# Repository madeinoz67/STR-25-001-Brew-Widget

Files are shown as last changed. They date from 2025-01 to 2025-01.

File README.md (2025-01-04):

# STR-25-001 Brew Widget

ESP32 Based Tilt Hydrometer

## Project Features

- All in one PCB inspired by [iSpindel - DIY electronics Hydrometer](https://www.ispindel.de/)

## Resources

Below are some handy resource links.

* [KiCad](https://www.kicad.org/) is a Cross Platform and Open Source Electronics Design Automation suite.
* [cookiecutter-kicad](https://github.com/madeinoz67/cookiecutter-kicad) a cookiecutter template for KiCad Projects.

## Authors

* **Stephen Eaton** - *Initial Work* - [github](https://github.com/madeinoz67)

See also the list of [contributors](https://github.com/madeinoz67/brew-widget/AUTHORS.rst) who participated in this project.

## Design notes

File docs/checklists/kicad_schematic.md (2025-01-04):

## KiCad Schematic Checklist - initial project setup

- [ ] Ensure the latest version of KiCad is installed and up-to-date.
- [ ] Add JLPCB Fabrication Toolkit Plugin to KiCad.
- [ ] Add JLPCB Kicad library as a submodule in kicad library folder 'git submodule add https://github.com/CDFER/JLCPCB-Kicad-Library.git'
- [ ] Add Strobotics Kicad library as a submodule in kicad library folder 'git submodule add https://github.com/madeinoz67/kicad-library.git'
- [ ] Stack-up aligns with manufacturer capabilities.
- [ ] Schematic template is set up correctly with the project name, revision, and date.

## ESP32 Schematic Checklist

- [ ] ESP32 is correctly placed and oriented, antenna has clearance.
- [ ] ESP32 is connected to the correct power and ground nets.
- [ ] GPIO 34 is only used for input.
- [ ] GPIO 35 is only used for input.
- [ ] GPIO 36 is only used for input.
- [ ] GPIO 39 is only used for input.
- [ ] Do Not Use GPIO 6 (used for flash)
- [ ] Do Not Use GPIO 7 (used for flash)
- [ ] Do Not Use GPIO 8 (used for flash)
- [ ] Do Not Use GPIO 9 (used for flash)
- [ ] Do Not Use GPIO 10 (used for flash)
- [ ] Do Not Use GPIO 11 (used for flash)

## Power Supply Schematic Checklist - schematic design

- [ ] For battery powered projects, ensure the battery management circuit is included.
- [ ] Ensure reverse polarity protection is included.
- [ ] Ensure Poly Fuses are included and sized correctly.

## KiCad Schematic Checklist - schematic design

- [ ] Ensure all components are correctly annotated.
- [ ] Ensure all components are correctly placed and connected.
- [ ] Ensure all components are correctly labeled.
- [ ] Ensure all power and ground connections are robust and able to handle the expected current.
- [ ] Ensure all components are correctly connected to the correct nets.
- [ ] Ensure all components are correctly connected to the correct power and ground nets.
- [ ] Ensure all components are correctly populated with their appropriate footprints.
- [ ] Ensure all components are correctly connected to the correct footprints.
- [ ] Ensure all components are correctly populated with their appropriate value.
- [ ] Ensure all components are correctly populated with their appropriate reference designator.
- [ ] Ensure all components are correctly populated with their appropriate part number.
- [ ] Ensure all components are correctly populated with their appropriate manufacturer's part number.
- [ ] Ensure all components are correctly populated with their appropriate manufacturer's datasheet.
- [ ] Ensure all components can handle expected voltages.
- [ ] Mark all unused pins as no connect.
- [ ] Ensure the schematic is not missing any parts.
- [ ] Ensure the schematic is not missing any power or ground connections.
- [ ] Ensure the schematic is not missing any footprints.

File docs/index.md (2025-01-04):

# Welcome to STR-25-001 Brew Widget

ESP32 Based Tilt Hydrometer based on the iSpindel

--8<-- "./README.md"

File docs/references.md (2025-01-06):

- [iSpindel - DIY electronics Hydrometer](https://www.ispindel.de/)
- Alternative Firmware - [Gravity Mon](https://mp-se.github.io/gravitymon/index.html)

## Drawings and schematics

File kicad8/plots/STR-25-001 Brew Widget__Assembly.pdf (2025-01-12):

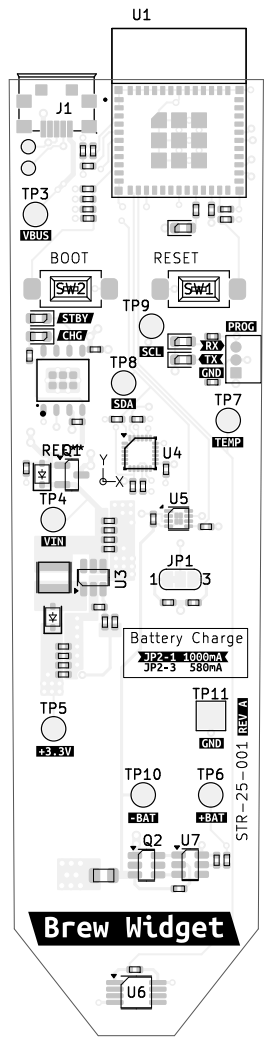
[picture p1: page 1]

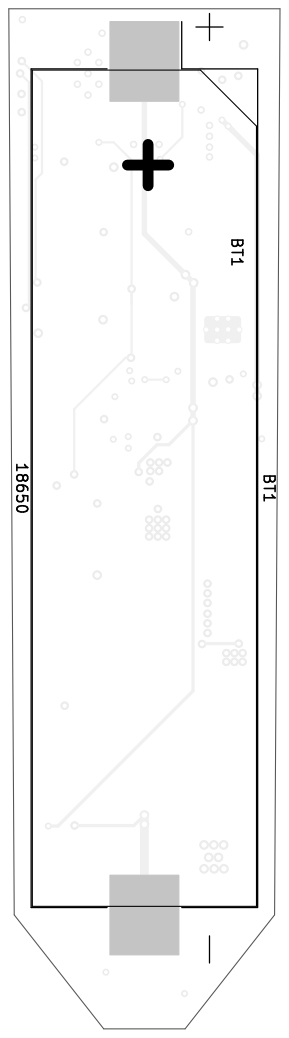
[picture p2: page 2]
D Date: 2025-01-04 KiCad; E.D.A. 8.0.7 Size: A4; Rev: A; Id: 1/1 Title: ESP32 Based Tilt Hydrometer File: STR-25-001; Brew Widget.kicad_pcb Sheet: Black; And; White; BOT Author: Stephen; Eaton Project Github:; https://github.com/madeinoz67/brew-widget License: CC-A-SA; Board2Pdf:; Black; BOT -; Page 2/2 ¹⁸⁶⁵⁰

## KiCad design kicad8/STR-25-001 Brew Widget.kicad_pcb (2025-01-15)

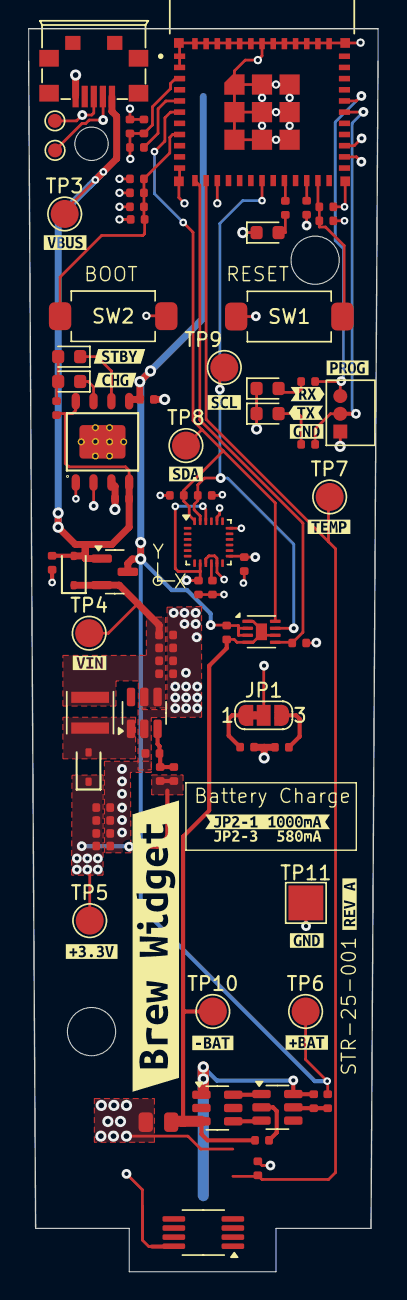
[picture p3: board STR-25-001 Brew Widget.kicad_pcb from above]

Board: 4 copper layers, 25.0 x 88.9 mm, 95 parts (1 on the bottom side), 36 nets.

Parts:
BT1: 18650; BatteryHolder_Keystone_1042_1x18650
C1, C3, C4, C12, C14, C20, C21: 100nF; C_0402
C2: 4.7uF; C_0402
C5, C6, C7, C8, C10, C15, C18, C19: 10uF; C_0402
C9, C17: 1uF; C_0402
C11, C16: 100pF; C_0402
C13: 10pF; C_0402
D1, D2, D3, D5: RED; LED_0603_1608Metric
D4, D7: B16WS; D_SOD-323
D6: GREEN; LED_0603_1608Metric
J1: USB_B_Micro; MICRO-USB-SMD_5P_C40945
JP1: SolderJumper_3_Bridged12; SolderJumper-3_P1.3mm_Bridged12_RoundedPad1.0x1.5mm_NumberL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
L1: 22uH,540mA; IND_LQH3NPZ220MMEL
PROG1: Pogo Pin 1.27mm; PROG_1x3_1.27
Q1: IRLML6401; SOT-23
Q2: FS8205A; SOT-23-6
R1, R2, R3, R4, R9, R19: 10kΩ; R_0402
R5, R8, R10: 1.5kΩ; R_0402
R6, R7, R18: 4.7kΩ; R_0402
R11: 100kΩ; R_0402
R12, R14: 2kΩ; R_0402
R13: 1.2kΩ; R_0402
R15: 68kΩ; R_0402
R16: 15kΩ; R_0402
R17: 100Ω; R_0402
R20: 0Ω; R_0805
R21: 1kΩ; R_0402
SW1, SW2: SPST 8x3.6; SW_SMD_SPST_8x3.6
TP1, TP2: TestPoint; TestPoint_Pad_D1.0mm
TP3, TP4, TP5, TP6, TP7, TP8, TP9, TP10: TestPoint; TestPoint_Pad_D2.0mm
TP11: TestPoint; TestPoint_Pad_2.5x2.5mm
U1: ESP32-C3-MINI-1-N4
U2: TP4056; ESOP-8_L4.9-W3.9-P1.27-LS6.0-BL-EP
U3: MT3608; SOT-23-6
U4: MPU-6500; InvenSense_QFN-24_3x3mm_P0.4mm_NoMask
U5: MAX17048; TDFN-8-1EP_2x2mm_P0.5mm_EP0.8x1.2mm
U6: DS18B20U; MSOP-8_3x3mm_P0.65mm
U7: DW01A; SOT-23-6
kibuzzard-67835DB7: G***; kibuzzard-67835DB7
kibuzzard-67835E0F: G***; kibuzzard-67835E0F
kibuzzard-67835E03: G***; kibuzzard-67835E03
kibuzzard-67835E3B: G***; kibuzzard-67835E3B
kibuzzard-67837AE8: G***; kibuzzard-67837AE8
kibuzzard-67837E72: G***; kibuzzard-67837E72
kibuzzard-678345AF: G***; kibuzzard-678345AF
kibuzzard-678345CB: G***; kibuzzard-678345CB
kibuzzard-678345D9: G***; kibuzzard-678345D9
kibuzzard-678345E8: G***; kibuzzard-678345E8
kibuzzard-678346A0: G***; kibuzzard-678346A0
kibuzzard-6783457B: G***; kibuzzard-6783457B
kibuzzard-67834543: G***; kibuzzard-67834543
kibuzzard-67834564: G***; kibuzzard-67834564
kibuzzard-67834594: G***; kibuzzard-67834594
kibuzzard-67834607: G***; kibuzzard-67834607
kibuzzard-67834787: G***; kibuzzard-67834787
kibuzzard-67836539: G***; kibuzzard-67836539
kibuzzard-67836544: G***; kibuzzard-67836544

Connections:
+3.3V: C4.1, C5.1, C6.1, C13.1, C14.1, C16.1, C17.1, C18.1, C19.1, D7.1, R1.1, R2.1, R3.1, R4.1, R6.1, R7.1, R9.1, R15.1, R18.1, R19.1, TP5.1, U1.3 (3V3), U4.8 (VDDIO), U4.13 (VDD), U4.22 (nCS), U6.8 (V_{DD})
+BATT: BT1.1 (+), C15.1, C20.1, Q1.3 (D), R17.1, TP6.1, U2.5 (BAT), U5.2 (CELL), U5.3 (VDD)
-BATT: C20.2, Q2.3 (S2), R20.1, R21.2, TP10.1, U5.1 (CTG), U5.4 (GND), U5.6 (QSTRT), U5.9 (EP)
/-BATT_NOPROT: BT1.2 (-), C21.2, Q2.1 (S1), U7.6 (GND)
/FB: C13.2, R15.2, R16.1, U3.3 (FB)
/PROG: JP1.2 (C), U2.2 (PROG)
/VIN: C7.1, C8.1, C9.1, C11.1, D4.1, L1.1, Q1.2 (S), TP4.1, U3.4 (EN), U3.5 (IN)
/VOUT: D7.2, L1.2, U3.1 (SW)
/~CHG: D5.1 (K), U2.7 (~CHRG)
/~STBY: D6.1 (K), U2.6 (~STDBY)
EN: C2.1, C3.1, R3.2, R4.2, SW2.2, U1.8 (EN)
GND: C1.2, C2.2, C3.2, C4.2, C5.2, C6.2, C7.2, C8.2, C9.2, C10.2, C11.2, C12.2, C14.2, C15.2, C16.2, C17.2, C18.2, C19.2, D1.1 (K), D2.1 (K), D3.1 (K), J1.5 (GND), PROG1.1 (GND), R11.2, R13.2, R14.2, R16.2, R20.2, SW1.1, SW2.1, TP11.1, U1.1 (GND), U1.2 (GND), U1.11 (GND), U1.14 (GND), U1.36 (GND), U1.37 (GND), U1.38 (GND), U1.39 (GND), U1.40 (GND), U1.41 (GND), U1.42 (GND), U1.43 (GND), U1.44 (GND), U1.45 (GND), U1.46 (GND), U1.47 (GND), U1.48 (GND), U1.49 (GND_THERMAL), U1.49_2 (GND_THERMAL), U1.49_3 (GND_THERMAL), U1.49_4 (GND_THERMAL), U1.49_5 (GND_THERMAL), U1.49_6 (GND_THERMAL), U1.49_7 (GND_THERMAL), U1.49_8 (GND_THERMAL), U1.49_9 (GND_THERMAL), U1.50 (GND), U1.51 (GND), U1.52 (GND), U1.53 (GND), U2.1 (TEMP), U2.3 (GND), U2.9 (EP), U3.2 (GND), U4.9 (AD0), U4.11 (FSYNC), U4.18 (GND), U4.20 (RESV), U6.4 (GND)
GPIO6: R8.1, U1.20 (IO6)
GPIO9: C1.1, R2.2, SW1.2, U1.23 (IO9)
unnamed: D1.2 (A), R5.2
unnamed: D2.2 (A), R8.2
unnamed: D3.2 (A), R10.2
unnamed: D5.2 (A), D6.2 (A), R12.2
unnamed: JP1.1 (A), R13.1
unnamed: JP1.3 (B), R14.1
unnamed: Q2.6 (G1), U7.1 (OD)
unnamed: Q2.4 (G2), U7.3 (OC)
unnamed: R1.2, U1.5 (IO2)
unnamed: R9.2, U1.22 (IO8)
unnamed: C12.1, U4.10 (REGOUT)
unnamed: R21.1, U7.2 (CS)
unnamed: C21.1, R17.2, U7.5 (VCC)
RX_IN: PROG1.3 (RX), R5.1, U1.31 (IO21/TXD0)
SCL: R6.2, TP9.1, U1.18 (IO4), U4.23 (SCL), U5.7 (SCL)
SDA: R7.2, TP8.1, U1.6 (IO3), U4.24 (SDA), U5.8 (SDA)
TEMP: R18.2, TP7.1, U1.13 (IO1), U6.1 (DQ)
TX_IN: PROG1.2 (TX), R10.1, U1.30 (IO20/RXD0)
USB_D+: J1.3 (D+), TP2.1, U1.27 (IO19/USB_D+)
USB_D-: J1.2 (D-), TP1.1, U1.26 (IO18/USB_D-)
VBUS: C10.1, D4.2, J1.1 (VCC), Q1.1 (G), R11.1, R12.1, TP3.1, U2.4 (VCC), U2.8 (CE)
~BAT_ALERT: R19.2, U1.12 (IO0), U5.5 (~ALRT)

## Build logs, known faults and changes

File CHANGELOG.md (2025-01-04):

# Changelog

## [v0.0.1](https://github.com/madeinoz67/STR-25-001-Brew-Widget/tree/v0.0.1) (2025-01-04)

[Full Changelog](https://github.com/madeinoz67/STR-25-001-Brew-Widget/compare/6f07e134ea0ccfb9fa12e33e374a57ec09a87928...v0.0.1)

\* *This Changelog was automatically generated by [github_changelog_generator](https://github.com/github-changelog-generator/github-changelog-generator)*

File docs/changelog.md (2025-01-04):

---
title: Changelog
---
--8<-- "./CHANGELOG.md"

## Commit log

2025-01-04 initial project commit
    [STR-25-001 Brew Widget.kicad_pcb, STR-25-001 Brew Widget.kicad_sch]
2025-01-04 changes before bed
    [ESP32.kicad_sch, Power_sch.kicad_sch, STR-25-001 Brew Widget.kicad_sch]
2025-01-06 Removed unused schematic sheets
    [ESP32.kicad_sch, Power_sch.kicad_sch]
2025-01-06 Ready for Schematic Review
    [STR-25-001 Brew Widget.kicad_sch]
2025-01-06 updated kicad-library
2025-01-09 Started PCB Layout
    [STR-25-001 Brew Widget.kicad_pcb, STR-25-001 Brew Widget.kicad_sch]
2025-01-11 PCB routed and all 3d models correct, needs final review
    [STR-25-001 Brew Widget.kicad_pcb, STR-25-001 Brew Widget.kicad_sch]
2025-01-11 Added TP labels on top silkscreen
    [STR-25-001 Brew Widget.kicad_pcb]
2025-01-11 Fix DRC
    [STR-25-001 Brew Widget.kicad_pcb]
2025-01-11 Added Fiducals
    [STR-25-001 Brew Widget.kicad_pcb, STR-25-001 Brew Widget.kicad_sch]
2025-01-12 Finalising deisgn, first checks review done
    [STR-25-001 Brew Widget.kicad_pcb, STR-25-001 Brew Widget.kicad_sch]
2025-01-12 BOM generated
    [STR-25-001 Brew Widget.kicad_pcb, STR-25-001 Brew Widget.kicad_sch]
2025-01-15 Changed to Buck Regulator using MT3406 Changed from DW01A on battery protection to AP9101C due to better low voltage protection
    [STR-25-001 Brew Widget.kicad_pcb, STR-25-001 Brew Widget.kicad_sch]
